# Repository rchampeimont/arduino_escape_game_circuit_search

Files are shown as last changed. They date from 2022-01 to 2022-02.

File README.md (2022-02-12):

# arduino_escape_game_circuit_search
See it in action in this YouTube video: https://www.youtube.com/watch?v=KEcAGj6aC5s

Used in an escape game where players had to find 3 circuits and solder their wires to a "main computer" (Arduino and its main circuit). When this is done, a code in morse is releaved using the buzzer.

Each circuit can have a lot of useless components just for the story-telling but the only thing that really matters is its resistance (the only really connected components are resistor(s)). Each circuit has a different resistance (1 kΩ, 10 kΩ, 100 kΩ) allowing the Arduino to check wether the correct circuits are connected to the right wires.

When each circuit is connected on the right wires, an LED with light up to show connection is good. When all 3 are connected, the buzzer will play a secret password in morse code.

## Schematic
The circuits that players are supposed to find and connect are resistors R5, R7 and R9 in the schematic. Matching resistors R4, R6 and R8 are on the Arduino-attached main circuit (like all other components) and allow to check that an equivalent resistance is connected by checking that the voltage in the middle point is half of the reference voltage.
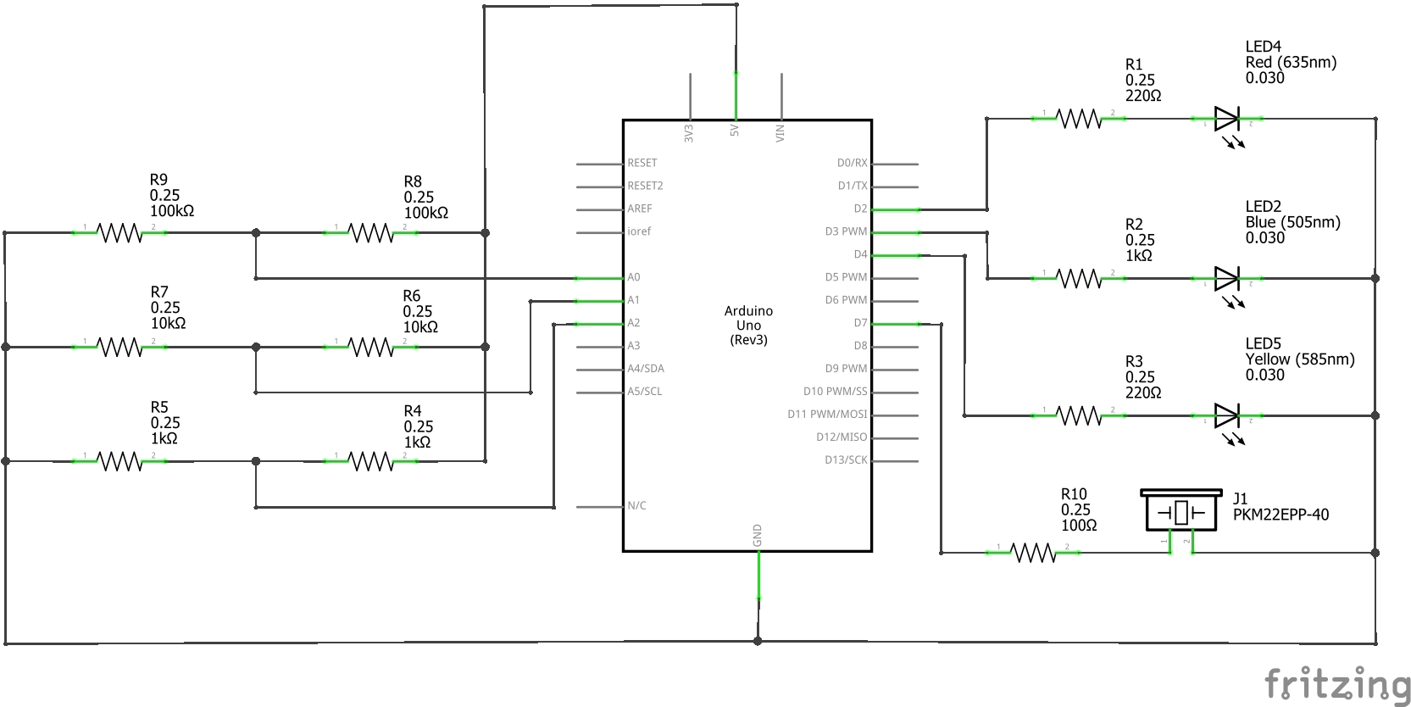
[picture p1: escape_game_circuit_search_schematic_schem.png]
Schematic


## Photos
Here is what the assembled circuit looks like:

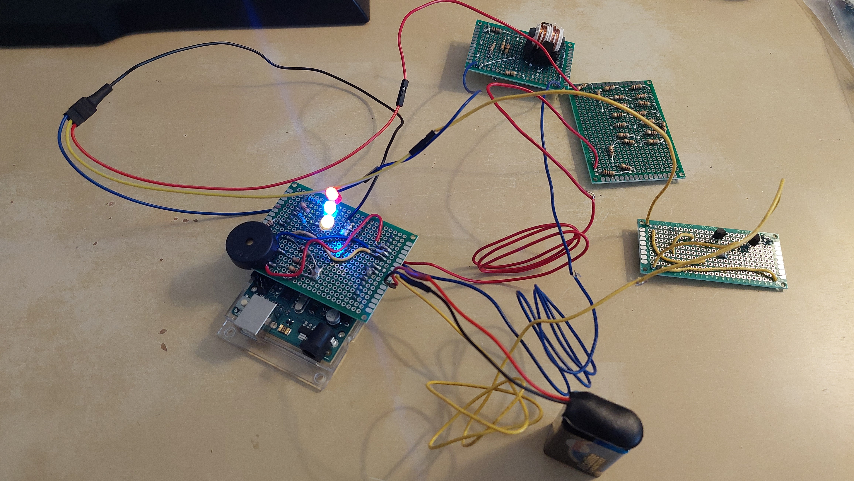
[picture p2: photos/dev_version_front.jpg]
Photo of development version - Front

The circuits with the blue and yellow wires are in fact only one resistor (resp. 10 kΩ and 100 kΩ), and no current goes throught the other components. The circuit with red wires is composed of ten 100 Ω resistors which together make 1 kΩ (and some other resistors are just for decoration).

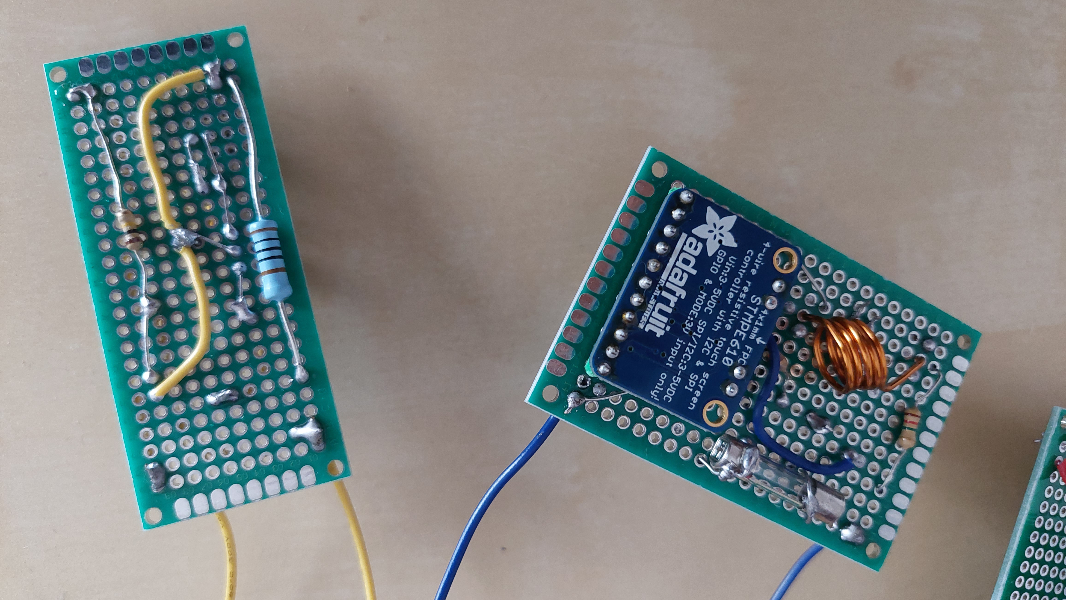
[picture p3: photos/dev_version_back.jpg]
Photo of development version - Back of circuits


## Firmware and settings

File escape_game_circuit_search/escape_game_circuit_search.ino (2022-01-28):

// Code designed for Arduino Uno R3

// Uses https://github.com/ridencww/cww_MorseTx 1.2.0
#include <cww_MorseTx.h>

const int NUMBER_OF_CIRCUITS = 3;
const int ANALOG_INPUTS[NUMBER_OF_CIRCUITS] = { A2, A1, A0 };
const int LED_OUTPUTS[NUMBER_OF_CIRCUITS] = { 2, 3, 4 };
const int ALLOWED_DELTA = 100;
const int SECONDS_CONTACT_BEFORE_CONSIDERED_SOLVED = 5;

// Morse settings
const int BUZZER_PIN = 7;
const int CW_SPEED = 5; // morse speed
const int TONE_FREQ = 500; // buzze tone Hz
cww_MorseTx morse(LED_BUILTIN, CW_SPEED, BUZZER_PIN, TONE_FREQ);

// Secret message to transmit when puzzle is solved
#define SECRET_MESSAGE "VOLET"

unsigned long solvedSince = 0;

void setup() {
  Serial.begin(9600); // for debug
  delay(1000);
  
  pinMode(LED_BUILTIN, OUTPUT);
  pinMode(BUZZER_PIN, OUTPUT);

  for (int i=0; i<NUMBER_OF_CIRCUITS; i++) {
    pinMode(LED_OUTPUTS[i], OUTPUT);
  }

  Serial.println("Ready");
}

void loop() {
  bool solved = true;
  for (int i=0; i<NUMBER_OF_CIRCUITS; i++) {
    const int val = analogRead(ANALOG_INPUTS[i]);
    //Serial.print(val);
    //Serial.print(" ");
    if (val > 512 - ALLOWED_DELTA && val < 512 + ALLOWED_DELTA) {
      digitalWrite(LED_OUTPUTS[i], HIGH);
    } else {
      solved = false;
      digitalWrite(LED_OUTPUTS[i], LOW);
    }
  }
  //Serial.println("");

  if (solved) {
    if (solvedSince == 0) {
      solvedSince = millis();
    }
  } else {
    solvedSince = 0;
  }

  if (solvedSince != 0 && millis() > solvedSince + 1000*SECONDS_CONTACT_BEFORE_CONSIDERED_SOLVED) {
    morse.send(SECRET_MESSAGE);
    delay(5000);
  }
  
  delay(100);
}

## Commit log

2022-01-09 create schematic
    [escape_game_circuit_search_schematic.fzz]
2022-01-09 export PNG of schematic
2022-01-09 blue LED is very bright so use a 1kohm resistor
    [escape_game_circuit_search_schematic.fzz]
2022-01-09 play morse message when solved
    [escape_game_circuit_search.ino]
2022-01-15 add piezzo to schematic
    [escape_game_circuit_search_schematic.fzz]
2022-01-15 Revert "make it less verbose"
    This reverts commit d4d79af140cafef036c9f069d598bb1694e71db6.
    [escape_game_circuit_search.ino]
2022-01-15 make it less verbose
    without bug this time
    [escape_game_circuit_search.ino]
2022-01-28 use pin 7 for buzzer for practical reasons
    [escape_game_circuit_search_schematic.fzz]
2022-01-28 replace by soldered version
